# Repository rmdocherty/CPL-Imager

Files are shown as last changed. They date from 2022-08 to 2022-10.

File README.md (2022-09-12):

# CPL-Imager
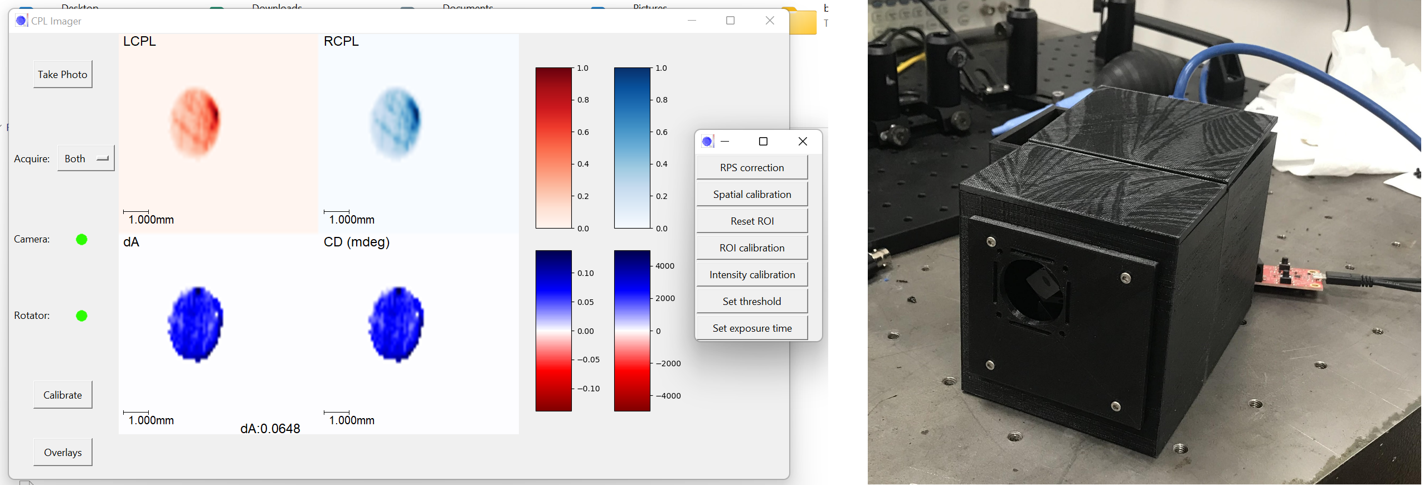
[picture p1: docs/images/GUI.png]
GUI screenshot


CPL-Imager is the control software for a low-cost, compact imaging system for Circularly Polarized Light (CPL). This repository contains the Python source code for the software, installation instructions and scripts, instrument assembly instructions (including .stl files for 3D printing) and a user manual for the instrument.

The instrument consists of a fresnel rhomb (which converts CPL to linearly polarised light), followed by a linear polariser in a piezoelectric rotation mount and a Thorlabs scientific camera. CPL-Imager controls the rotation of the piezomotor, ensuring subsequent images taken by the camera are of alternating handedness (i.e Left-CPL then Right-CPL then Left-CPL etc.). These LCPL and RCPL images are then combined to calculate differential absorbance (dA) and Circular Dichroism (CD) and these four quantities are then displayed on a live view in the GUI.

## Features:
- Ability to pause the rotator such that only LCPL or RCPL is imaged - useful for calibration as there is no rotator induced delay.
- A variety of calibration options: 
    - Setting the region-of-interest of the camera.
    - Correcting first-order defects relative to a reference polarization state.
    - Indicating if the camera is oversaturated.
    - Masking to eliminate stray light effects.
    - Setting a pixels-per-mm value based on a reference object.
- Visual overlays like a scale tick, axes, grid lines and a cursor based intensity readout allowing for point based measurement.
- User configurable colourmaps 
- The software also works for the 2-CCDI setup where two cameras and a polarized beamsplitter are used in place of the piezoelectric rotator.

## Usage
Once all the prerequisites described in ``install`` are setup, run ``python CPL_Imager.py`` from this directory to start the software (or run the script in an IDE of your choice). 

The respository structure is as follows:
- ``build`` contains all the .STL files needed to 3D print the casing (and sample holders) for the camera.
- ``docs`` contains the manual (inc. instrument assembly instructions) and quick start guide.
- ``docs/installation.txt`` contains instructions to set up the libraries and dlls needed for both the software and the Thorlabs cameras.
- ``photos`` is where images taken by the camera are stored, as well as containing some images used by the software (for icons etc)
- ``config.json`` contains options for the software in .json format, including ROIs, spatial calibration data and the colourmaps used by the software
- The rest of the ".py" files are source code for the software:
    - ``CPL_Imager.py`` is the entry point for the software, which detects and initalises the cameras used.
    - ``rotator.py`` controls the ELL14 piezoelectric rotator
    - ``cameras.py`` controls the connected camera(s) and puts the images taken onto a queue
    - ``colourmapper.py`` colourmaps the image data from the cameras and combines the two input images into a four panel output for display
    - ``GUI.py`` handles the user interface: displaying the live data, handling user interaction and issuing commands to the camera/rotator etc.

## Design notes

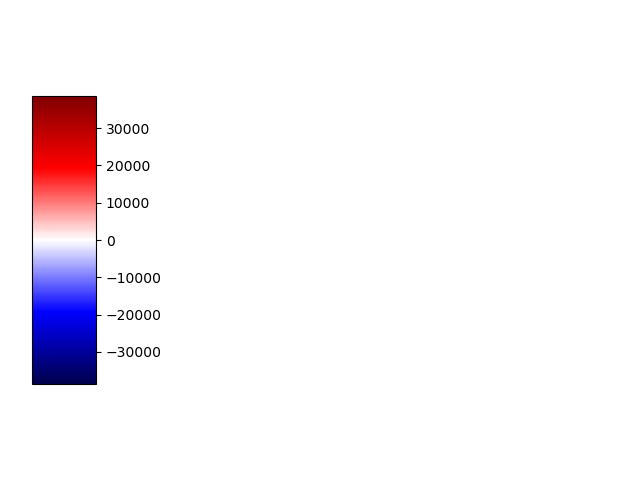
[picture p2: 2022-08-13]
photos/colorbar.png

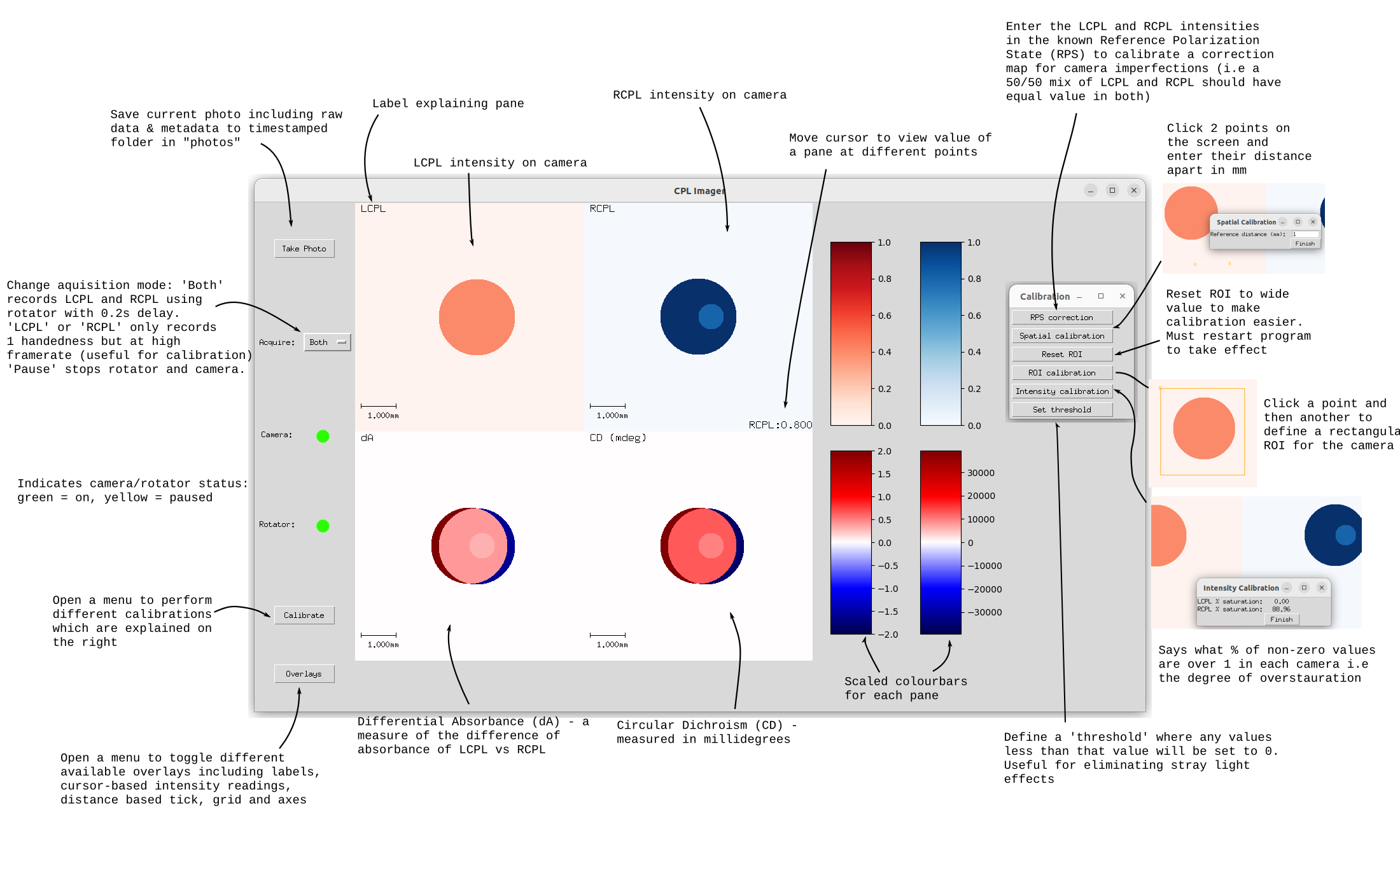
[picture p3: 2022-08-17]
docs/quickstart.png

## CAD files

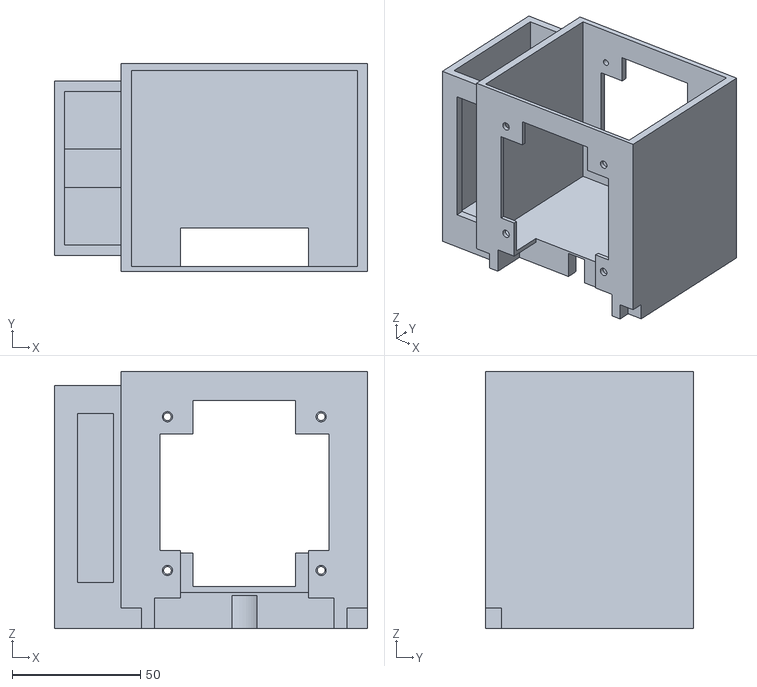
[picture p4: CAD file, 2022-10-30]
build/back_casing.stl
122.2 x 81.4 x 100.5

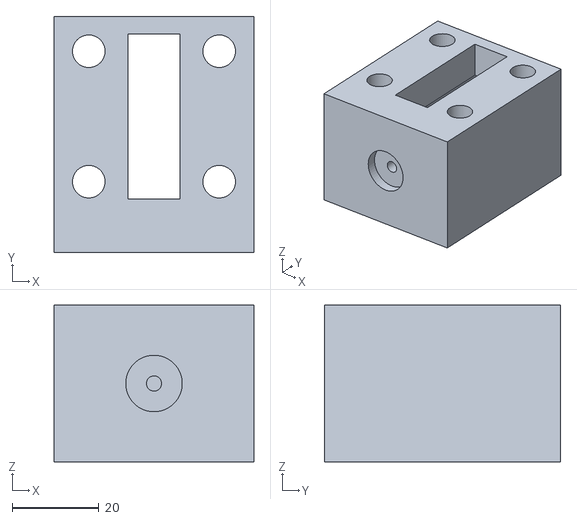
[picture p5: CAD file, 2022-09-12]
build/sample_holders/cuvette_holder_cube.stl
46.0 x 54.3 x 36.0

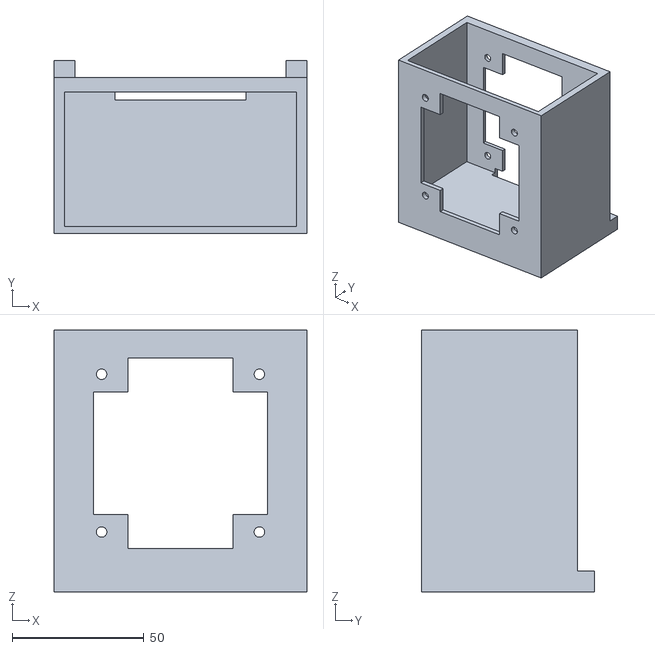
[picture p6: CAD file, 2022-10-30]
build/front_casing.stl
96.2 x 65.8 x 99.5

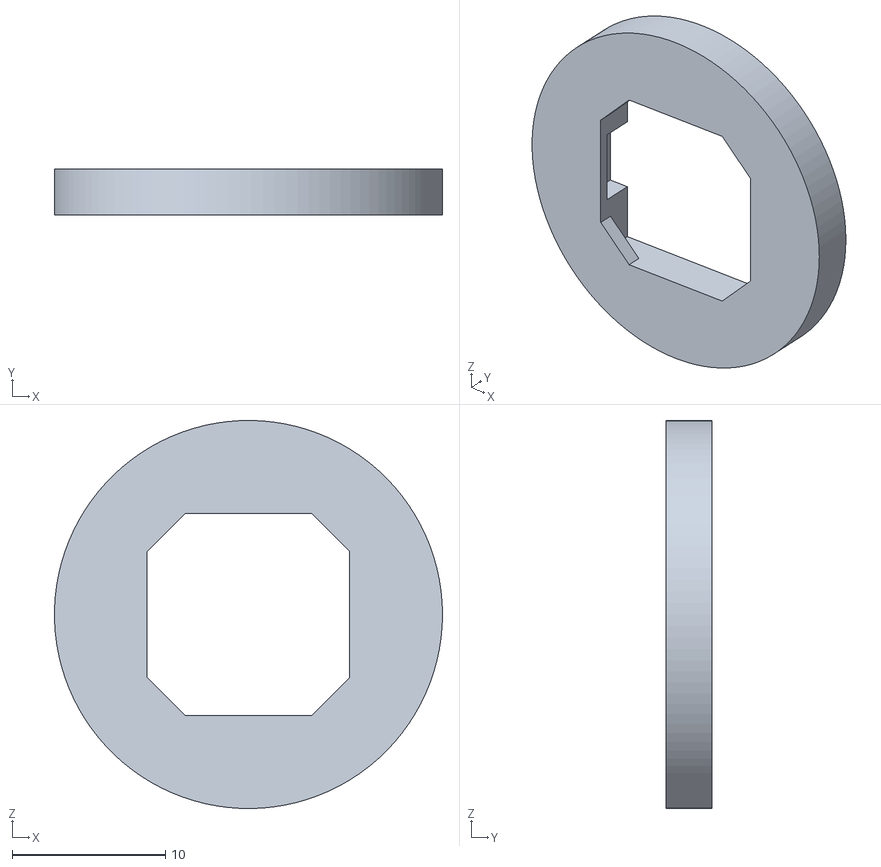
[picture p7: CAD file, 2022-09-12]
build/sample_holders/circle_design_front.stl
25.3 x 3.00 x 25.3

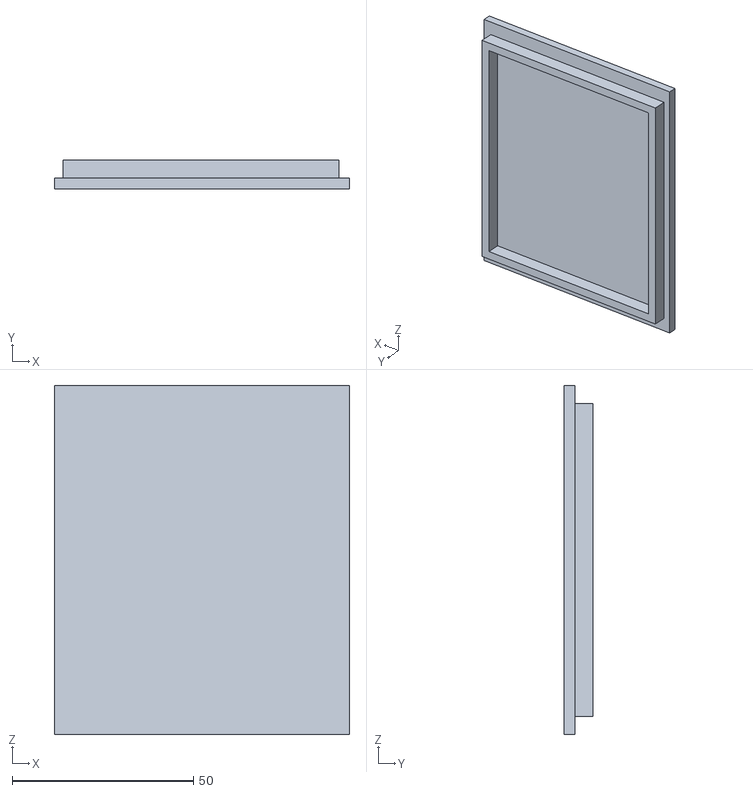
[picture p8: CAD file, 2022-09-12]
build/back_lid.stl
81.4 x 8.00 x 96.2

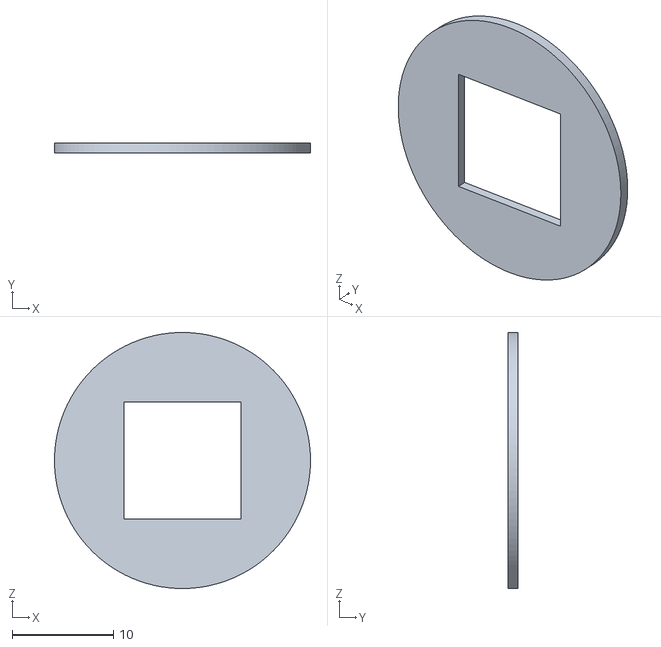
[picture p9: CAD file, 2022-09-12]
build/sample_holders/circle_design_back.stl
25.3 x 1.00 x 25.3

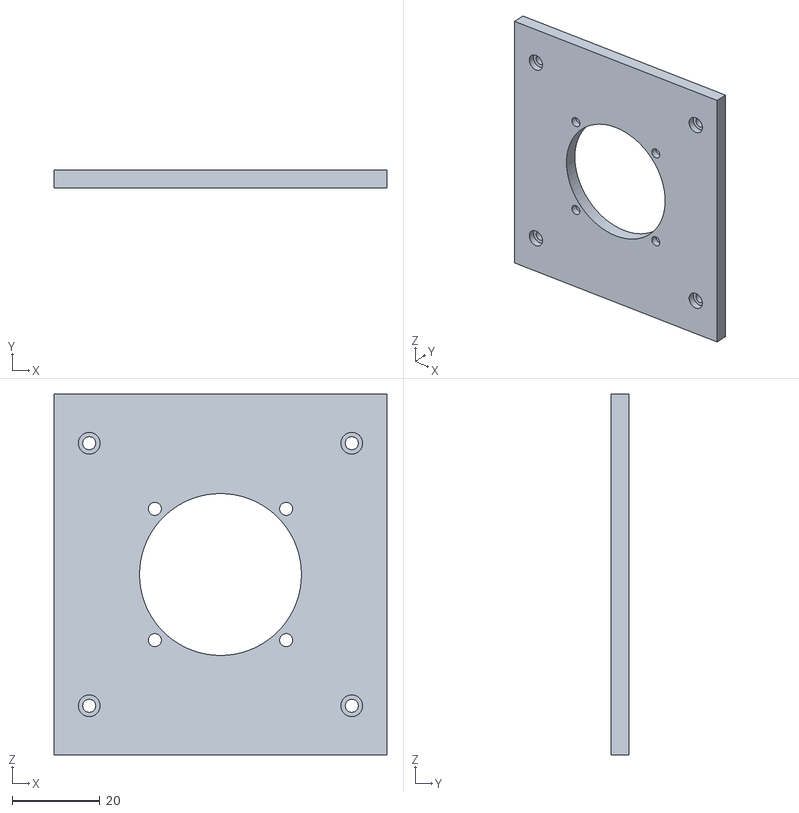
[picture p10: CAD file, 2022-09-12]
build/back_plate.stl
76.0 x 4.00 x 82.5

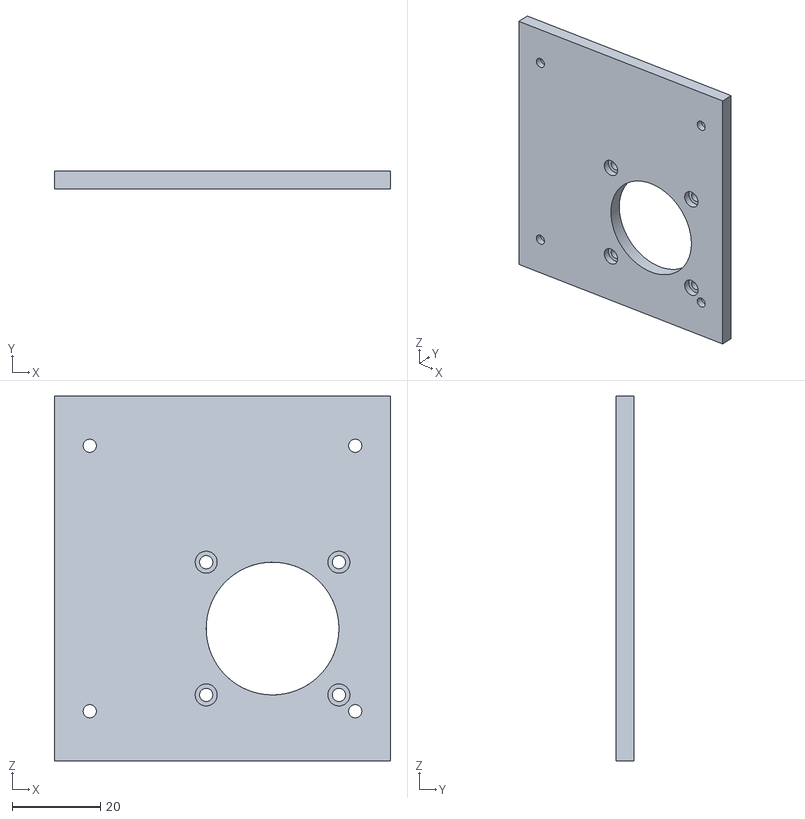
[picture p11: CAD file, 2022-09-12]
build/front_plate.stl
76.0 x 4.00 x 82.5

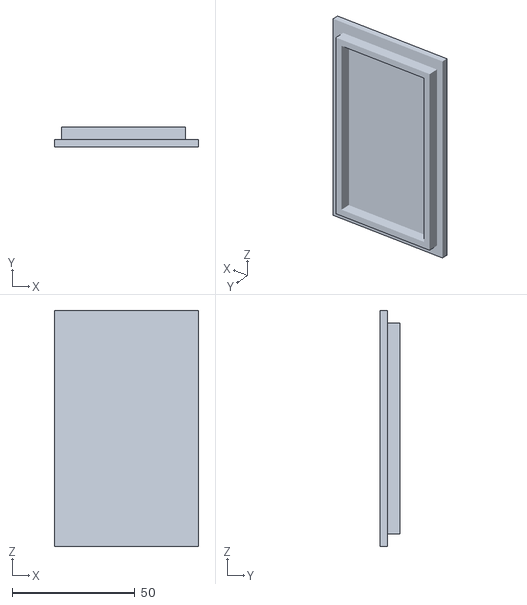
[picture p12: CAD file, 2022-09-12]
build/front_lid.stl
58.8 x 8.00 x 96.2

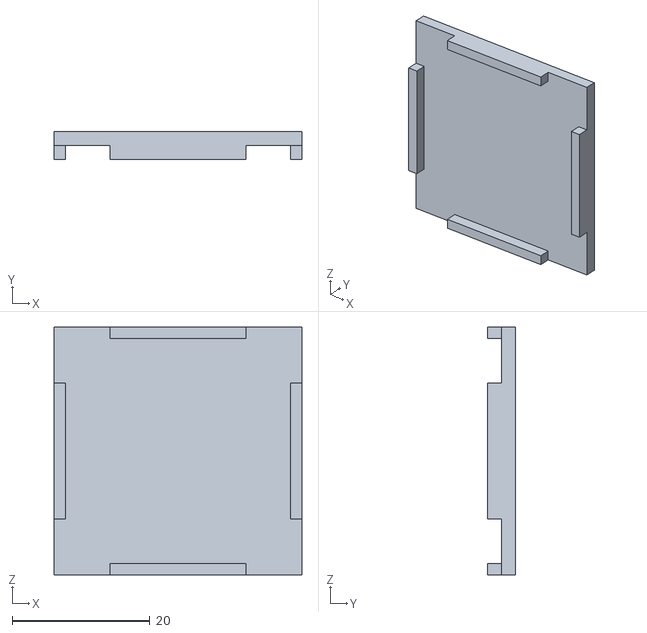
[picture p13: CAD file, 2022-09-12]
build/lens_cap.stl
36.0 x 4.00 x 36.0

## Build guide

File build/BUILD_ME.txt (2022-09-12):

This is, somewhat misleadingly, a physical 'build' folder, containing all the .stl files needed to assemble the casing as described in the manual. 
The .stl files in this current directory are for the casing, the ones in the 'sample_holder' directory are for sample holders you may wish to print.

Briefly, the circular sample holders are designed to fit in a Thorlabs 30mm cage plate, where the sample is placed in the space between the two plates,
then two Throlabs slip rings are screwed in either side to keep the thing in place. This cage plate with sample holder can then fit on a post or on the
cage system - potentially screwed onto the front of the casing. The sample cube is designed to have a cuvette (or thin film holder shaped like a cuvette)
placed into it. It then sits on a cage system or on a post in the beam path.

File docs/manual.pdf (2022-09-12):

CPL Imager Manual – Ronan Docherty

1

# CPL Imager Manual

## 1 Introduction:

Welcome to the manual for the CPL-Imager, a low-cost, compact circularly polarised imaging system. This system is designed to be quick to assemble and modular enough that it can be adapted to suit a variety of needs (in situ annealing, translation stages, magnets etc). It is primarily designed to image chiral thin-films, but can easily be applied to other contexts, like solutions.
The instrument consists of a Fresnel rhomb (which converts CPL to linearly polarised light), followed by a linear polariser in a piezoelectric rotation mount and a Thorlabs scientific camera. CPL-Imager controls the rotation of the piezomotor, ensuring subsequent images taken by the camera are of alternating handedness (i.e Left-CPL then Right-CPL then Left-CPL etc.). These LCPL and RCPL images are then combined to calculate differential absorbance and Circular Dichroism and these four quantities are then displayed on a live view in the GUI. Abbreviations used:
- CPL = Circularly Polarised Light. LCPL = Left-CPL, RCPL = Right-CPL
- dA = delta Absorbance
- CD = Circular Dichroism
- GUI = Graphical User Interface
- FR = Fresnel Rhomb
- TL = ThorLabs

## 2 Parts list:

### 1. Mounted quarter-wave Fresnel rhomb retarder (Thorlabs, FR600QM) 2. Wire grid polarizer (Thorlabs, WP25M-VIS) 3. Piezoelectric rotation mount (Thorlabs, ELL14K)

4. USB controlled monochrome Zelux® 1.6 MP CMOS Cameras are used (Thorlabs, CS165MU/M)
5. 6 mm focal length f = 1.4 Navitar lens (Thorlabs, MVL6WA)

### 6. Rods, 2", 4 pack (Thorlabs, ER2-P4) 7. Rods, 3", 4 pack (Thorlabs, ER3-P4)

8. 4-40 Capscrews; 3/8", 50 pack (Thorlabs, SH4S038)
9. 4-40 Setscrews; 1/2", cup-tipped, 50 pack (Accu, SSU-4-40-1/2-A2 or Amazon)

### 10. Black 3D printing ABS or PLA plastic (Amazon)

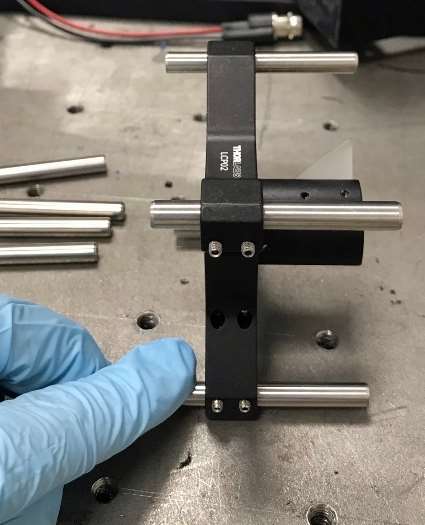
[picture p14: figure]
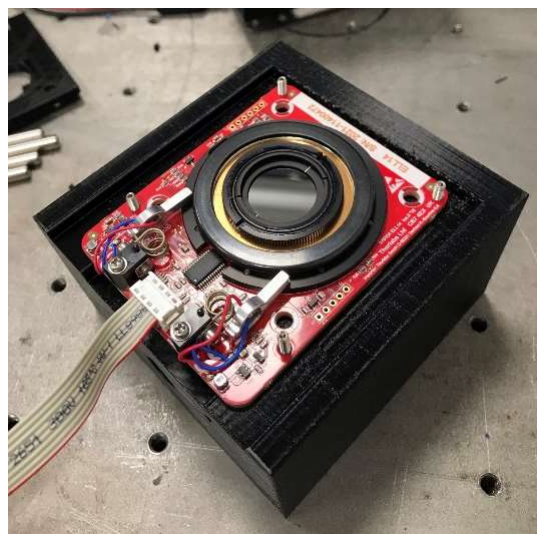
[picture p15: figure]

2

## 3 Assembly:

0) Print all the 3D printed parts found in the 'build' directory of this repo
1) Place the FR into the 30-60mm TL cage adapter, ensure it is aligned at 45° from the vertical then fix it in place with 2 slip rings. Screw in the 2" rods in to the 60mm spaced holes, ensuring the rods come in front of the adapter (i.e in the direction of the fresnel rhomb) and are evenly spaced. Leave some amount of the rod behind the adapter so that the adapter is not in direct contact with the rotator when resting on top.
2) Place this construction in the 3D printed front body, then screw the setscrews into the ends of rods facing away from the FR.

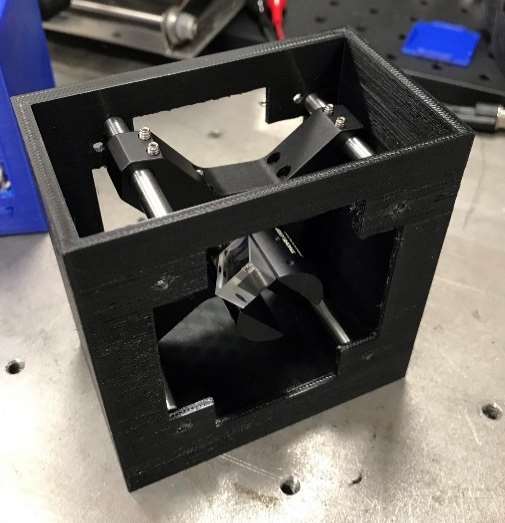
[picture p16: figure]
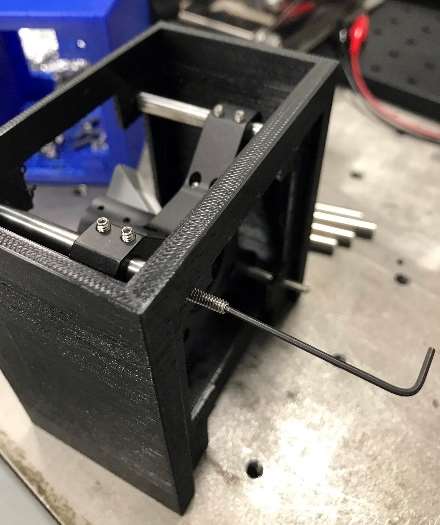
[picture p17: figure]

3) Place the linear polariser into the ELL14 rotator. Ensure the linear polariser is aligned at 0° to the vertical, even if the rotator casing is slightly angled (every ELL14 has a slightly different home angle, this is accounted for in rotator.py).
4) Place the ELL14 piezoelectric rotator on the back of the casing such that the setscrews poke through the holes in the rotator.
5) Place the 3D printed back body case onto the poking out screws. Be careful not to damage or knock any of the electronics on the piezo board whilst doing this (though the casing is designed to account for this)

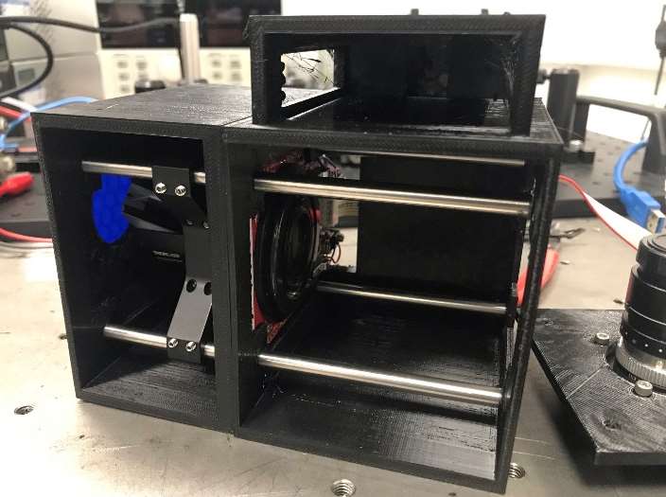
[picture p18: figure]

3

6) Starting from bottom to top, screw in the 3" rods to the setscrews in the back body casing by hand. This step is tough - there isn't a lot of give in the casing and there can be slipping. Be careful the rods don't hit the rotator.
7) Screw the capscrews through the back plate into the camera, then screw more capscrews through the reverse of the plate into the rods so the camera sits enclosed in the casing.

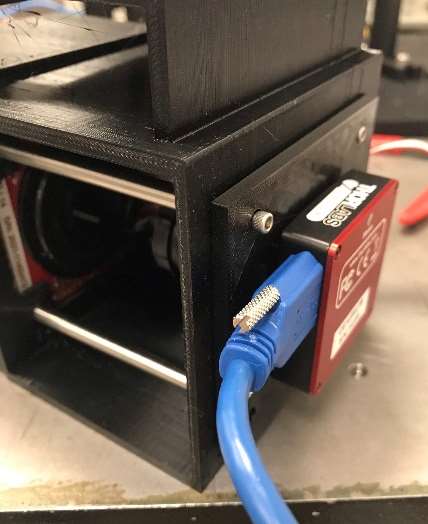
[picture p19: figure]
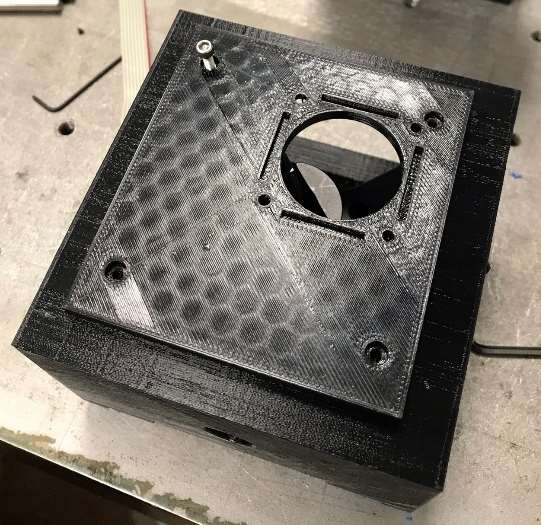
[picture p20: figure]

8) Screw the capscrews through the front plate into the rods inside the front body casing.
9) Place the piezorotator board ribbon cable into its space on the bottom of the back body, then plug the USBs from the camera and piezorotator board into either your computer or a Raspberry Pi.

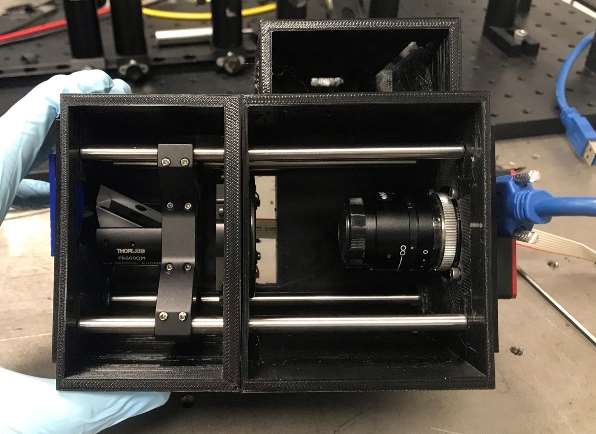
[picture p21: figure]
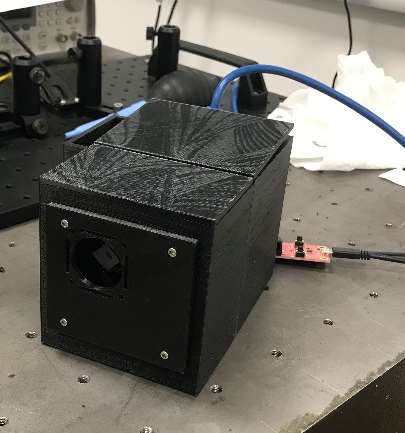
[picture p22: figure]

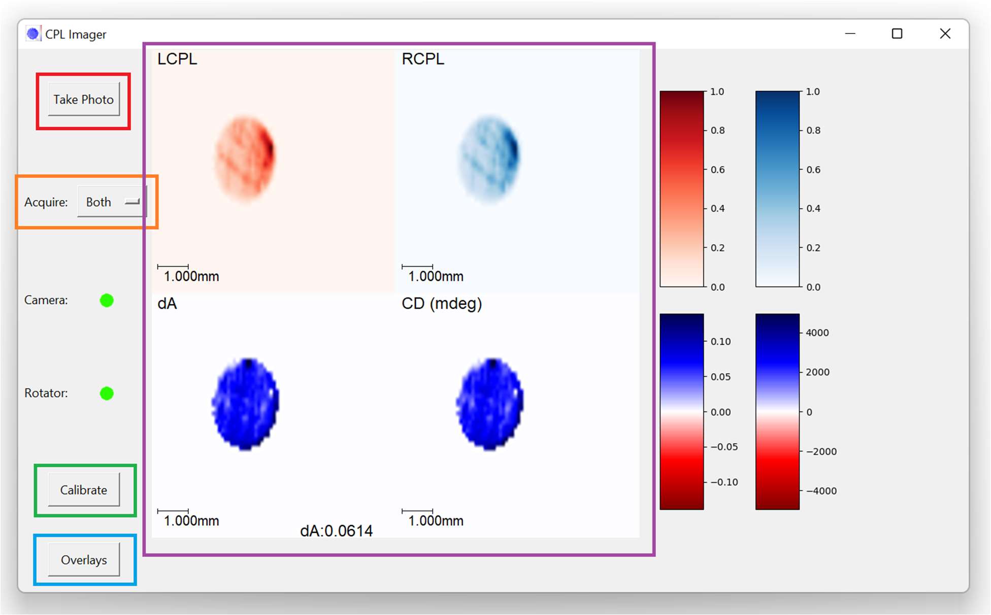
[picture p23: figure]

4

There is an alternate setup with 2 cameras and a polarised beamsplitter (rather than the piezorotator), but this is more expensive and has difficulty in aligning the 2 cameras. However, it has no associated rotator delay so can run with a higher framerate.

## 4 Software:

These following sections refer to the control software of the CPL-Imager. Certain sections are colour coded to refer to sections of the above GUI image. A handy quickstart guide is in the docs folder under the filename quickstart.png, which may be sufficient to understand the software.

## 4.1 Installation:

As with assembly, detailed installation instructions (including automated scripts) can be found in the installation.txt file, but to sum up:

### 1. Download the correct Thorlabs SDK from their website

(https://www.thorlabs.com/software_pages/ViewSoftwarePage.cfm?Code=ThorCam , on the ‘Programming Interfaces’ tab) for your system. If using a Raspberry Pi for the setup, email the Thorlabs tech support team at techsupport@thorlabs.com and ask for their experimental ARM SDK, where the .so files are compiled for the right instruction set.

5

### 2. Run whatever THORLABS_SDK_INSTALLATION_INSTRUCTIONS.txt says to do

for your system, and install the Python library in the "Python Toolkit" folder via pip or conda or whatever environment manager you use
3. Install the required Python libraries (numpy, matplotlib, Pillow, pyserial, also skimage if you want to try the 0 camera demo)

### 4. Run CPL_Imager.py either via the CLI or in an IDE of your choice

After that, you're all set!

## 4.2 Panel Layouts:

The software has 4 panels which show different data. The top two panels show the last readings of LCPL and RCPL intensity taken from the camera. The bottom two show dA and CD, two measures of the differential absorption of LCPL vs RCPL common in the literature. All 4 are colourmapped based on the colourmaps in config.json; the values of these colours can be read off the colourbars on the right hand side of the screen, where the colour bar position corresponds to the same data pane (i.e top left colourbar is LCPL).

## 4.3 Taking Photos:

Pressing the "Take Photo" button will take a photo of whatever is currently on the GUI screen and save it to a timestamped directory in the photos folder. This will contain a bitmap of the image, a .txt, .csv and .npy of the raw LCPL and RCPL data and a file describing the image metadata like any corrections applied or the pixels per mm of the images. LCPL data will be the left image and RCPL data will be on the right of the image (the same holds true for the data files).

## 4.4 Acquisition modes:

There are 4 possible acquisition modes of the software, available under the "Acquire" dropdown menu:
- Both: the rotator will rotate every 0.2 seconds, taking images of alternating handedness and displaying them on the screen. dA and CD will be calculated automatically and displayed as well. This mode has an associated 0.2s delay, and the rotator will burn out if run continuously for too a time, so be careful.
- LCPL / RCPL: the rotator will move to either the horizontal or vertical position, and the camera will capture images of a single handedness with a high framerate. As there is no rotator delay, the live view is much more responsive, so these modes are good for calibrating the system before taking images.
- Pause: both the rotator and camera will pause and the picture will be static. Useful if you have an image you want to examine or take a photo of.

6

## 4.5 Calibration:

Pressing the "Calibrate" button will open a sub-menu with a variety of useful calibration options:
- RPS correction: remove any samples in the beam path and set up your source to be a Reference Polarization State i.e a state with a 50:50 mix of LCPL and RCPL and where each intensity reading is just barely saturated. Then enter '1' in both forms and press submit then a correction mask will be generated which adjusts any spots that aren't of value 1. This correction then persists, so will apply when imaging a sample. This is intended to correct errors in the setup like optical aberrations.
- Spatial calibration: click two points on the screen separated by some reference distance, then enter the reference distance in mm into the popup and press 'Finish'. Then the spatial based overlays like ticks, axes and gridlines will automatically adjust to the new scale when toggled on in the 'Overlays' menu.
- Reset ROI: reset camera ROI back to a wide view (1024x1024). Useful for calibrating the ROI later.
- Calibrate ROI: click a point on the screen to act as the top-left corner of the ROI, then a rectangle will appear at the current cursor position showing a bounding box. Click a second point to define the other corner and finish the calibration.
- Intensity calibration: a popup will appear telling you the percentage of non-zero pixels in the LCPL or RCPL data that are 1 or above (i.e are saturated). When taking measurements it is preferable to have 0% saturation with as high an intensity as possible; you want to be just below the threshold of saturation.
- Set threshold: set a threshold intensity value below which any readings will be set to 0. Useful if there's weak stray light. Would recommend using this for calibration or visualising more so than taking data as any masked data won't be recorded, causing you to miss possible real signals. Setting a threshold will also cause the colourbars on the right to be reloaded.

## 4.6 Overlays:

These overlays appear over the data panes when toggled on in the menu (and are not saved to the photos):
- Change cmaps: there is a text field for each data pane - enter the name of a valid matplotlib colourmap for each and press finish, then the colourmaps will be updated. I recommend diverging colourmaps for dA and CD panes and converging colourmaps for LCPL and RCPL.

7

- Intensity: when toggled on, text will appear at the bottom of whichever data pane the cursor is on displaying the value of that pane at that point. This means the mouse can be used for quick data reading.
- Label: display text which explains which pane is which.
- Tick: a tick bar will appear on each pane showing the scale of the image. The size of the tick bar will be determined by your spatially calibrated pixels-per-mm value.
- Axes: axes will appear on each pane, again with a scale given by the pixel-per-mm value
- Grid: a grid will appear on each pane at the same positions as the axes but across the entire pane.

## 4.7 Source Code:

Source code is of course contained in the repo - modify to suit your needs. If you think it's a useful addition, please send a merge request. I have broadly tried to follow a Model-View-Controller framework where possible whilst also respecting the threaded nature of the Thorlabs camera code, but this has caused some rough edges.
The programme structure is as follows:
- CPL_Imager.py: entry point of the program, instantiates the camera, Thorlabs SDK, GUI and live view objects.
- colourmapper.py: handles the colourmapping for the data panes and the colourbars on the left hand side. Colourmaps based on matplotlib colourmaps and adjusts based on the max and min values on the screen. Also contains the definitions for delta absorbance and circular dichroism, which probably isn't the best place to hold the central equations but que sera.
- cameras.py: classes for the Thorlabs camera, handles the main loop of taking photos, sending the rotate command and dumping photos onto the correct queue.
- rotator.py: sends hex commands via pyserial to the rotator.
- GUI.py: handles the GUI – mostly buttons etc and logic around that, but also contains a live image display thread that grabs pairs of images from the separate queues, combines them, colourmaps them and places them onto the GUI.

8

## 5 Troubleshooting:

This section contains some common problems and suggested solutions:
- COM/USB port can’t be found for the rotator. Usually happens when program crashes during runtime and the port wasn’t closed properly. Unplug and plug in the rotator board USB and try again.
- I can’t see stuff on the screen! Check the camera ROI, shutter etc.
- I pressed ‘left’ on the acquisition dropdown but nothing changed! Probably the rotator getting strange – try changing it to ‘Right’ then back to ‘Left’.
- The Python Thorlabs library isn’t working! It can’t find the drivers! Try following the driver/.so file troubleshooting in the SDK. If still not working, check the windows_config.py file path is right (on Windows) or that you’ve run ldconfig properly on Linux.
- Permission error on /dev/ttyUSB{N} ! Your current user account doesn’t have USB permission. Run sudo chmod 777 /dev/ttyUSB{N} where {N} is some integer (i.e /dev/ttyUSB0)
- I’m using a Raspberry Pi and I’ve followed all the driver instructions properly but the Python library still won’t work! Make sure you’re using the ARM compiled version of the SDK – this isn’t available online, you have to email the Thorlabs support team for it.

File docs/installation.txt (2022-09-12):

STEP 0:
Clone or download this repo to your computer (I'm assuming this has already been done if you're reading this)

STEP 1:
Go to https://www.thorlabs.com/software_pages/ViewSoftwarePage.cfm?Code=ThorCam , click the 'Programming Interfaces' tab, then download the right .zip file for your system (*not* the DCx series one). Copy the zip file over to the CPL-Imager folder and extract there.

STEP 2 (WINDOWS):
Ensure the path to the SDK DLLs is the same as the path found in 'windows_setup.py' - this lets the Thorlabs camera Python library can find them later.

STEP 2 (LINUX):
*the following text for this step has been reproduced from THORLABS_SDK_INSTALLATION_INSTRUCTIONS.txt*
Copy (as root) the Camera SDK shared libraries to /usr/local/lib:

- libthorlabs_unified_sdk_main.so
- libthorlabs_unified_sdk_kernel.so
- libthorlabs_tsi_usb_driver.so
- libthorlabs_tsi_cs_camera_device.so
- libthorlabs_tsi_zelux_camera_device.so
- libthorlabs_tsi_camera_sdk.so

*added by me*
This can be done by running the following command in the SDK/Native_Toolkit/bin/Native_xx_lib where xx=32/64
sudo cp libthorlabs*.so /usr/local/lib

Run the following command (on Ubuntu Linux) to make the libraries available to applications:
sudo ldconfig -v

Copy the usb.rules file located in the same folder as this document to /etc/udev/rules.d.  If that folder does not exist, please create it.

STEP 3:
Install the Thorlabs camera Python library in the SDK/Python_Toolkit/ directory via the command line via pip or conda with a command like:
python.exe -m pip install thorlabs_tsi_camera_python_sdk_package.zip

STEP 4:
Install the required Python libraries using pip, these being numpy, matplotlib, Pillow and pyserial (if you want to test the 0 camera setup, skimage is also required).

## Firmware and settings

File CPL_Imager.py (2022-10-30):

#!/usr/bin/env python3
# -*- coding: utf-8 -*-
"""
Created on Fri Jul 30 10:51:34 2021

@author: ronan
"""

import queue, socket, pickle
import threading
from thorlabs_tsi_sdk.tl_camera import TLCameraSDK
from cameras import ImageAcquisitionThread, CompactImageAcquisitionThread, MockCamera, threaded, HybridIAT
from GUI import CPL_Viewer, LiveViewCanvas, platform, file_sep, icon_path
import tkinter as tk
import numpy as np


if platform == "linux" or platform == "linux2":
    pass
else:
    try:
        # if on Windows, use the provided setup script to add the DLLs folder to the PATH
        from windows_setup import configure_path
        configure_path()
    except ImportError:
        configure_path = None

class CPL_Imager():
    """
    CPL_Imager.

    Parent class that encapsulates the general program logic of the imaging system.
    Creates a GUI from GUI.py, grabs two cameras using the SDK, creates a camera_widget
    which is the live view canvas and throws it onto the Tkinter app. Starts (i.e arms)
    the two cameras, then their respective image threads. Once the Tkinter app closes it
    then stops those threads.
    """

    def __init__(self):
        self._root = tk.Tk()
        
        self._root.iconbitmap(f'{icon_path}')
        self._GUI = CPL_Viewer(master=self._root)
        self._root.title("CPL Imager")
        self._root.geometry("1400x800")
        col_count, row_count = self._root.grid_size()

        for row in range(row_count):
            self._root.grid_rowconfigure(row, maxsize=10)

    def _gen_image_acquisition_threads(self, cam1, cam2):
        return ImageAcquisitionThread(cam1, label="left"), ImageAcquisitionThread(cam2, label="right")

    def _gen_widget(self, image_queue1, image_queue2):
        camera_widget = LiveViewCanvas(parent=self._root, iq1=image_queue1,
                                       iq2=image_queue2, img_type="2cam")
        return camera_widget

    def _start_camera(self, cam):
        cam.frames_per_trigger_zero_for_unlimited = 0
        cam.arm(2)
        cam.issue_software_trigger()

    def _start_cameras(self, cam1, cam2):
        self._start_camera(cam1)
        self._start_camera(cam2)

    def run(self): #camera order should be 14358, 14071
        camera_list = sdk.discover_available_cameras()
        print(camera_list)
        with sdk.open_camera(camera_list[1]) as cam1:
            image_acquisition_thread_1 = ImageAcquisitionThread(cam1, label="left")
            self._start_camera(cam1)
            iq1 = image_acquisition_thread_1.get_output_queue()
            with sdk.open_camera(camera_list[0]) as cam2:
                image_acquisition_thread_2 = ImageAcquisitionThread(cam2, label="right")
                self._start_camera(cam2)

                iq2 = image_acquisition_thread_2.get_output_queue()
                camera_widget = self._gen_widget(iq1, iq2)
                self._GUI.set_camera_widget(camera_widget)
                image_acquisition_thread_1.start()
                image_acquisition_thread_2.start()

                print("Viewer starting")
                self._root.mainloop()

                image_acquisition_thread_1.stop()
                image_acquisition_thread_1.join()
                image_acquisition_thread_2.stop()
                image_acquisition_thread_2.join()
        return 0

    def _main_function(self, cam1, cam2):

        image_acquisition_thread_1, image_acquisition_thread_2 = self._gen_image_acquisition_threads(cam1, cam2)

        iq1 = image_acquisition_thread_1.get_output_queue()
        iq2 = image_acquisition_thread_2.get_output_queue()
        camera_widget = self._gen_widget(iq1, iq2)
        self._GUI.set_camera_widget(camera_widget)
        self._start_cameras(cam1, cam2)
        self._GUI.set_control_queue(image_acquisition_thread_1._control_queue) # check this later!
        image_acquisition_thread_1.start()
        image_acquisition_thread_2.start()

        print("Viewer starting")
        self._root.mainloop()

        image_acquisition_thread_1.stop()
        image_acquisition_thread_1.join()
        image_acquisition_thread_2.stop()
        image_acquisition_thread_2.join()

        print("Closing resources...")


class CPL_Imager_One_Camera(CPL_Imager):
    """
    CPL_Imager_One_Camera.

    A child class from CPL_Imager intended for use when only one camera is
    connected to the computer. First checks which 'handedness' of camera is
    attached i.e is it the LCPL or RCPL camera and switches the image queues
    accordingly (this is so it will be colourmapped correctly).
    """

    def _gen_image_acquisition_threads(self, cam1, cam2):
        return (ImageAcquisitionThread(cam1), cam2)

    def _start_camera(self, cam):
        cam.frames_per_trigger_zero_for_unlimited = 0
        cam.arm(2)
        cam.issue_software_trigger()

    def _start_cameras(self, cam1, cam2):
        self._start_camera(cam1)

    def run(self):
        self._camera_handedness = input("Which camera is plugged in - LCPL or RCPL?").lower()
        with TLCameraSDK() as sdk:
            camera_list = sdk.discover_available_cameras()
            print(camera_list)
            with sdk.open_camera(camera_list[0]) as cam1:
                self._main_function(cam1)


class Compact_CPL_Imager(CPL_Imager_One_Camera):
    """
    Compact_CPL_Imager.

    For use in the compact optical design - i.e a single camera and a linear
    polarizer on a rotating mount. Takes image every 0.2 seconds in alteranting
    polarizations.

    TODO:                                                          
    8) can you measure g_abs by just calibrating to light in w/out sample then putting sample in?          
    """

    def run(self):
        """Grab all available cameras and pass them into the main function."""
        self._camera_handedness = "LCPL"
        with TLCameraSDK() as sdk:
            camera_list = sdk.discover_available_cameras()
            with sdk.open_camera(camera_list[0]) as cam:
                self._main_function(cam)

    def _gen_widget(self, image_queue1, image_queue2):
        camera_widget = LiveViewCanvas(parent=self._root, iq1=image_queue1,
                                       iq2=image_queue2)
        return camera_widget

    def _gen_compactIAT(self, camera):
        return CompactImageAcquisitionThread(camera)

    def _main_function(self, cam):
        image_acquisition_thread = self._gen_compactIAT(cam)
        camera_widget = self._gen_widget(image_acquisition_thread.get_output_queue(),
                                         image_acquisition_thread.get_output_queue_2())
        self._GUI.set_camera_widget(camera_widget)
        self._GUI.set_control_queue(image_acquisition_thread._control_queue)
        self._start_camera(cam)
        image_acquisition_thread.start()

        print("Viewer starting")
        self._root.mainloop()

        image_acquisition_thread.stop()
        image_acquisition_thread.join()
        print("Closing resources...")


class ComputerSocket:
    def __init__(self, ip, port):
        self._image_queue_1 = queue.Queue(maxsize=1)
        self._image_queue_2 = queue.Queue(maxsize=1)
        self.s = socket.socket(socket.AF_INET, socket.SOCK_STREAM)
        try:
            self.s.connect((ip, port))
            self.connected = True
            #self.s.listen()
        except:
            print("Error when opening, closing socket")
            self.s.close()
    def put(self, item): #act as a queue
        #obj = {"type": "control", "data": item}
        self.write_obj(item)
    def write_obj(self, obj):
        self.s.send(obj.encode())
        #send_data(obj)
    def close(self):
        self.s.close()

    def listen(self):
        while self.connected == True:
            try:
                byte = self.s.recv(8388608)
                msg = pickle.loads(byte)
                if msg:
                    if self.msg['Name'] == "LCPL":
                        self._image_queue_2.put(np.frombuffer(msg['data']))
                    else:
                        self._image_queue_1.put(np.frombuffer(msg['data']))
            except EOFError:
                print('radn out of input')

class CPL_Imager_Hybrid(Compact_CPL_Imager):
    def run(self):
        """Grab all available cameras and pass them into the main function."""
        self._camera_handedness = "LCPL"
        self._main_function()
    def _main_function(self):
        local_IAT = ComputerSocket("169.254.234.142", 50001)
        camera_widget = self._gen_widget(local_IAT._image_queue_1,
                                         local_IAT._image_queue_2)
        self._GUI.set_camera_widget(camera_widget)
        self._GUI.set_control_queue(local_IAT)
        network_thr = threading.Thread(target=local_IAT.listen)
        print("Viewer starting")
        network_thr.start()
        self._root.mainloop()
        local_IAT.close()
        network_thr.join()
        print("Closing resources...")


class CPL_Imager_No_Camera(CPL_Imager):
    """
    CPL_Imager_No_Camera.

    Another child class of CPL_Imager, designed for use with no cameras i.e as
    a demo. Really just an extension of the ideas of One_Camera.
    """

    def _gen_image_acquisition_threads(self, cam1, cam2):
        return (cam1, cam2)

    def _start_cameras(self, cam1, cam2):
        pass

    def run(self):
        cam1 = MockCamera(label="left")
        cam2 = MockCamera(label="right")
        self._main_function(cam1, cam2)

mode = "normal"
if __name__ == "__main__":
    with TLCameraSDK() as sdk:
        camera_list = sdk.discover_available_cameras()
        print(f"Operating with {len(camera_list)} cameras!")
        if len(camera_list) == 2: #beamsplitter design
            imager = CPL_Imager()
        elif len(camera_list) == 1: #compact design
            imager = Compact_CPL_Imager()
        elif len(camera_list) == 0:
            if mode =='hybrid':
                imager = CPL_Imager_Hybrid()
            else:
                imager = CPL_Imager_No_Camera()
        else:
            raise Exception("Too many cameras!")
            
    imager.run()

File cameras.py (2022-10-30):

#!/usr/bin/env python3
# -*- coding: utf-8 -*-
"""
Created on Fri Jul 30 12:14:46 2021

@author: ronan
"""
import rotator
import serial
import threading
import socket
import pickle
from functools import wraps
from thorlabs_tsi_sdk.tl_camera import TLCameraSDK

import queue
import numpy as np
from sys import platform
import json
from time import sleep
try:
    from skimage import draw
except ImportError:
    print("Couldn't import skimage, 0 camera demo will not work.")
import random
from colourmapper import read_from_json
from time import sleep

np.random.seed(1)
IMG_HEIGHT = 360 # can go at least as high as 1000x1000 - don't know what upper limit is!
IMG_WIDTH = 360


def threaded(f): #maybe there is problem here - all the extrea threads never close
    """
    Execute the given function or method in another thread
    """
    @wraps(f)
    def wrapper(*args, **kwargs):
        thr = threading.Thread(target=f, args=args, kwargs=kwargs, daemon=True)
        #thr.isDaemon(True)
        thr.start()
    return wrapper


def clearQueue(queue):
    while not queue.empty():
        queue.get()
    return 0

class ImageAcquisitionThread(threading.Thread):
    """
    ImageAcquisitionThread.

    This class derives from threading.Thread and is given a TLCamera instance during initialization. When started, the
    thread continuously acquires frames from the camera and converts them to 8 bit np array image. These are placed in a
    queue.Queue object that can be retrieved using get_output_queue(). The thread doesn't do any arming or triggering,
    so users will still need to setup and control the camera from a different thread. Be sure to call stop() when it is
    time for the thread to stop.
    """

    def __init__(self, camera, label="left"):
        super().__init__() #pdon't include class inside super as this breaks inheritance for child classes!
        self._camera = camera
        self._camera.roi = (0, 0, 1500, 1500)
        self._previous_timestamp = 0
        self._label = label

        self._bit_depth = camera.bit_depth
        self._camera.image_poll_timeout_ms = 10  # Do not want to block for long periods of time. was 0!!!
        self._image_queue = queue.Queue(maxsize=2)
        self._stop_event = threading.Event()
        self._camera.exposure_time_us = 10100 #was 11000 
        self._get_roi_from_file()

    def _get_roi_from_file(self):
        """Grab corresponding (left or right) ROI config from the file, else
        use defaults."""
        try:
            coords = read_from_json("roi_"+self._label)
            ROI = (coords[0], coords[1], coords[2], coords[3])
            print(f"Setting ROI as {ROI}")
            self._camera.roi = ROI
        except (IOError, ValueError):
            print("Error generating ROI from file, falling back to default")
            pass

    def get_output_queue(self):
        """Getter for the queue object."""
        return self._image_queue

    def stop(self):
        """Stop thread object."""
        self._stop_event.set()

    def _get_image(self, frame):
        # no coloring, just scale down image to 8 bpp
        # bit shift by self._bit_depth -8 to right i.e divides image_buffer by 2** (bit_depth - 8)
        scaled_image = frame.image_buffer >> (self._bit_depth - 8)
        return scaled_image / 255  #rescaled from 0 - 1 for colourmap

    def run(self):
        """
        Run.

        While thread is running grab frames from camera, create a 8 bit image from them
        and put them onto the queue.
        """
        while not self._stop_event.is_set():
            try:
                frame = self._camera.get_pending_frame_or_null()
                if frame is not None:
                    np_image = self._get_image(frame)
                    self._image_queue.put_nowait(np_image)
            except queue.Full:
                pass
            except Exception as error:
                print("Encountered error: {error}, image acquisition will stop.".format(error=error))
                break
        print("Image acquisition has stopped")
        self._camera.disarm()
        self._camera.dispose()


class CompactImageAcquisitionThread(ImageAcquisitionThread):
    """
    CompactImageAcquisitionThread.

    This class derives from IAT. Has 2 queues, one for each polarization.
    Does the same stuff as IAT but each time it takes a photo it rotates the
    piezo motor 90 degrees and swaps which queue to put the image into.
    """

    def __init__(self, camera, align=True):
        super().__init__(camera)
        self._imaging_LCPl = True
        self._image_queue = queue.Queue(maxsize=1)
        self._image_queue_2 = queue.Queue(maxsize=1)
        self._rotator = self.connect_to_rotator()
        self._mode = "Both"
        self._control_queue = queue.Queue(maxsize=2)

    def connect_to_rotator(self):
        if platform == "linux" or platform == "linux2":
            port = "/dev/ttyUSB"
        else:
            port = "COM"
        connected_rot = False
        for i in range(0, 4):
            try: # try all diff com/usb ports for rotator
                if connected_rot is False:
                    port_n = port + str(i)
                    test_port = serial.Serial(port_n, baudrate=9600)
                    connected_rot = True
            except:
                pass
        if connected_rot is False:
            raise Exception("No rotator!")
        return rotator.Rotator(test_port)

    def get_output_queue_2(self):
        """Getter for the queue object."""
        return self._image_queue_2

    def _rotate_mount(self, degrees):
        self._rotator.rotate_to_angle(degrees)
    
    def change_cam_settings(self, ROI=None, exposure_time_us=None):
        self._camera.disarm()
        if ROI is not None:
            self._camera.roi = ROI
        if exposure_time_us is not None:
            self._camera.exposure_time_us = exposure_time_us()
        self._camera.frames_per_trigger_zero_for_unlimited = 0
        self._camera.arm(2)
        self._camera.issue_software_trigger()

    def get_camera_image_old(self, iq, toggle=True, iq2=None):
        try:
            frame = self._camera.get_pending_frame_or_null()
            if frame is not None:
                pil_image = self._get_image(frame)
                iq.put_nowait(pil_image)
                if toggle:
                    self._imaging_LCPl = not self._imaging_LCPl  # toggle bool
                if iq2 is not None:
                    null = np.zeros_like(pil_image)
                    iq2.put_nowait(null)
        except queue.Full:
            pass
        except Exception as error:
            print("Encountered error: {error}, image acquisition will stop.".format(error=error))
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

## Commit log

2021-07-29 Fixed up colourmap to always return a single image. Added class to mock to simulate a camera operation, hopefully will be able to simulate two simultaneous cameras + tk window soon by modifying LiveV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
    [colourmapper.py]
2021-07-29 Added a mock camera class to simulate expected camera output for testing. Changed up LiveViewCanvas to take 2 image queues and then colourmap them appropriately. Mock camera stuff all works so that's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
    [colourmapper.py]
2021-07-30 Created CPL_Imager.py, the entry point to the program and the file that hosues the main class. Basically just initialises the SDK and opens the right cameras and creates the widgets etc. Have made a 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
    Have also made a GUI class that houses all the TKinter button logic and packing arrangements etc. For some reason seems to work best when both the GUI and the canvas are packed into root.
    Next commit will be refactoring the code - placing the mock camera and the LiveViewCamera from live view into a file called cameras.py and getting rid of the colour code and script stuff, and throwin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
2021-07-30 As promised moved canvas to GUI.py and ImageAcquisition thread and MockCamera to cameras.py, all works fine.
    Next job is commenting/documenting the functions properly and maybe writing a README.txt.
2021-07-30 Added documentation to cameras, GUI and CPL_Imager.
2021-08-02 Added code for the one camera rotating LP compact design. Inherits from previous code but uses 2 queues for one camera and waits for rotator to finish moving. Need to go through and add documentation.
2021-08-02 Added documentation. Camera works but frame rate v slow - is this because ofhaving 2 live views and 2 cameras or is my code bad?
2021-08-03 Fixed the inheritance problems with super(class, self) and replaced with just super(), this means child classes can inherit properly and has cut down on redundant functions. Also created a SingleCame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
    [CPL_Imager.py, GUI.py, cameras.py]
2021-08-06 Added ability to change cmaps during runtime. Adds a new button to GUI with popup window w/ 4 text fields where you can enter in a mpl cmap string for that mode. Framerate seems choppy atm on simulat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
    [GUI.py, colourmapper.py]
2021-08-10 Rotator now works, requires Ftdi library though (and also probably the drivers but these are mainlined in Linux kernel). Need to clean up old code on there and add proper docs. Think about putting th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
2021-08-12 Cleaned up uncessary prints, added some comments.
2021-08-12 Found rotator offest, added some setter functions to motor. Will refactor to cut down on duplicated code soon.
2021-08-13 Don't acc need FTDI library, can just use pySerial. Not sure if this will work on non-linux devices?
2021-08-19 Fixed up g_em code so it results in something between 0 and 1 rather than -1 and 1.
    [GUI.py, cameras.py, colourmapper.py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]
2021-08-23 Saved a backup as a zip and removed the mock interface code. Changed up the script initialsing so doesn't do cmd prompt anymore to speed up testing.
    [CPL_Imager.py, cameras.py, rotator.py]
2021-08-25 Added temporary alignment mode that halts rotation, should remove later. Moved HORIZONTAL and VERTICAL to rotator.py so Rotator init angle consistent with later rotation angles. Last commit before bi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
2021-08-25 Added option to toggle live video on and off by creating a control queue accessible to the camera and the GUI. Camera now has 3 modes: "Live", "Photo" and "Off". Live: continuous rotation and image t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
2021-08-26 Added calibration menu to GUI and associated functions. Calibration is three stages 1) intensity, 2) RPS and 3) ROI. Intensity: type a % threshold into menu and press button. If % of saturated pixels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
    [CPL_Imager.py, GUI.py, cameras.py]
2021-08-26 Started on ROI config. Bit hacky but decided best way to config was just to make quick script to do this w/ Live Viewer code, and have camera load from file at start. Still ROI setting code in rest w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
2021-08-27 Basically just finished hacky ROI calibration. Last commit before transferring intensity and interactive ROI calibration to ROI_calibration.py from CPL_viewer.
2021-08-27 Took ROI and intensity calibrations into the ROI_calibration.py file, now displays text of current saturations and lets you place crosses to map out ROI manually. Took out the equivalent code from GU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
    [GUI.py, colourmapper.py, rotator.py]
2021-09-01 Fixed 2 camera setup - need to use separate context managers for each camera and get IAT & start cam before starting new context manager. Then can start these threads and throw onto GUI as normal. No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
    [CPL_Imager.py, GUI.py, cameras.py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]
2021-09-03 Lots of changes. 2 cam setup working. Added mouseover intensity reading (first 2 modes use converging cmap so just read in resized img and convert to grayscale to measure intensity, but for g_em cmap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
    [CPL_Imager.py, GUI.py, cameras.py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]
2021-09-17 Added back in the mock camera to test changes to GUI n stuff & rejigged the CPL imager stuff to make inheritance easier. Changed how get_intensity_at_cursor works by getting rid of the image based in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
    [CPL_Imager.py, GUI.py, cameras.py]
2021-09-17 Added colourbar to RHS of CPL Imager. Done by creating the colorbar in colourmapper.py and creating a new canvas in GUI and packing to RHS of LiveView canvas. Currently a bit dodgy as need to create 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
2021-09-17 Added a type of imager check to the GUI so only 2 cam inputs are flipped. Removed some old files.
    [CPL_Imager.py, GUI.py]
2022-08-08 Old code from PhD pres: better mock camera testing etc. Also added code to make it work on windows. Later should make sure this works on both platforms with same script (i.e check platform at runtime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
2022-08-08 Started working on the redesign: streamlined GUI, started adding scaffolding for new calibration features (need to think of best way to do tick spacing).
    [CPL_Imager.py, GUI.py]
2022-08-09 Started working on spatial calibration stuff: nearly all working except need to make GUI menu functions toggle state of LiveView attributes. Works by choosing a nice round number that will fit into s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
2022-08-09 Got all overlays working via checkboxes in the menu. Got the program working cross platform by changing ports/file separators based on platform. Cleaned up GUI. Now plan is to rework config files int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
    [CPL_Imager.py, GUI.py, cameras.py]
2022-08-09 Moved old scripts to 'old' folder to clean up repo. Made the whole thing use a single JSON config file (rather than 4 different text files) - much cleaner! Made it so you can calibrate the spatial st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
2022-08-09 Began work on a 'free camera' mode which will run one camera only but put onto both queues. Also fixed slight visual offset when clicking for calibration. Last commit before switch to 4-panel GUI beg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
    [CPL_Imager.py, GUI.py, cameras.py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]
2022-08-10 GUI resolutions have all changed? Have stopped predefining geometry and let tkinter do it for me. Fixed lag - needed to delete old canvas objects every time I redraw the canvas. Now is smooth as butt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
    [CPL_Imager.py, GUI.py, cameras.py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]
2022-08-14 Added intensity calibration option, added icon to all menus. Consider making a menu class that does all this stuff automatically so cut down on repeated code.
2022-08-14 Added thresholding code (i.e set camera output to 0 if below certain value)
2022-08-23 Fixed rotator by conmparing to ELLO program - now rotates between 0 and 90 exactly (assuming LP installed perfectly horizontally in ELL14). Made GUI overlays work when camera paused by moving out of 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
    [GUI.py, cameras.py, rotator.py]
2022-08-30 Made the system work by averaging over certain number of frames rather than single one from live view. Last commit before swapping order of 'LCPL' and 'RCPL' data as is currently wrong way around.
    [CPL_Imager.py, GUI.py, cameras.py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]
2022-08-30 Fixed LPCL/RCPL sign convention by swapping the two images in the np array in hstack. Added a proviso in manual.md. No need for any other changes.
    [GUI.py, cameras.py]
2022-08-30 Added parts list and finished assembly instructions
2022-08-31 Fixed LCPL RCPL only modes wrt previous fix to definitions
    [cameras.py]
2022-09-12 More docs stuff + 3D design files
    [back_casing.stl, back_lid.stl, back_plate.stl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]
2022-09-13 Got program to automatically detect which com/usb port the rotator is plugged into (i.e no longer hardcocded as COM3 or ttyUSB0). Removed old comments.
    [CPL_Imager.py, GUI.py, cameras.py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]
2022-10-30 Added more hybrid stuff but not fully implementted. Added the changes to the stl files (interlocks for the front and back case)
    [back_casing.stl, front_casing.stl]
